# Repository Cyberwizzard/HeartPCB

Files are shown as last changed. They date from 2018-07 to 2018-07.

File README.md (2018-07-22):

# HeartPCB - PCB with LEDs forming an illuminated and animated heart
Firmware and PCB layout for a heart shaped PCB with LEDs.

## About
I designed this PCB and the corresponding firmware as a wedding present for all guests attending. The PCB is the size and shape of a standard coaster, so that it could be used during the party by all guests to put their glass on top of it. When they go home they get a small plastic back containing the components to complete the kit.

The PCB has 18 LEDs, divided into 10 groups and is driven by a) an Arduino Pro Mini of b) statically lit by soldering some pads together.

## Option A
The simple build involves 8 x 47 Ohm and 2 x 150 Ohm resistors, a USB mini connector and 18 red 3mm LEDs.

Solder in place and solder the pads in the middle of the heart together. When plugged in, all LEDs will turn on.

## Option B
When using with an Arduino Pro Mini, there are a number of animations which are played. There are 2 buttons: the brightness button changes the brightness of all LEDs, the fast-forward button switches to the next animation. It supports a demo mode in which animations automatically cycle: hold down brightness until the animation is interrupted and the top-middle LED is on, keep pushing as more and more LEDs come on blinking. The more LEDs blink, the longer the animation is displayed before switching to the next. Set to 0 blinking LEDs to stop automatically forwarding.

The firmware saves the settings and state in the EEPROM (with write wear-levelling) every time the animation changes or the settings are changed.

The component list is 8 x 47 Ohm, 2 x 150 Ohm, 12 x 10k Ohm, USB mini connector, 18 red 3mm LEDs, 2 x 5x5mm push buttons, 1 x 470uF or 1000uF capacitor, 1 x Arduino Pro Mini (ATMEGA328 5V 16MHz)

### Troubleshooting
I had one board getting corrupted after the USB power bank feeding it got empty - my guess is EEPROM corruption. It got stuck loading some invalid stuff and the error LEDs kept turning on.
I fixed this by making error reporting optional and disabled (for production).

If the board does not start correctly due to EEPROM corruption, hold down any button while booting it.
It will now ignore the EEPROM and start the first animation. Press the fast-forward button to skip to the next animation and saving new settings to EEPROM.

## When using this project
Feel free to base your own gift off this design; drop me a note if you do as its nice to hear if this stuff is used again.

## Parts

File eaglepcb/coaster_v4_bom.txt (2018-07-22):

Partlist exported from D:/Users/Documents/eagle/heart_coaster/coaster_v4.sch at 4-5-2018 10:43

1  x 1000uF POLARIZED CAPACITOR
1  x USB CONNECTOR
1  x PIN HEADER 1X6
18 x LED RED 3MM
2  x RESISTOR 0207/7 150 OHMS
12 x RESISTOR 0207/7 10K OHMS
8  x RESISTOR 0207/7 47  OHMS
2  x MICROSWITCH 5MM
1  x ARDUINO PRO MINI (ATMEGA328)

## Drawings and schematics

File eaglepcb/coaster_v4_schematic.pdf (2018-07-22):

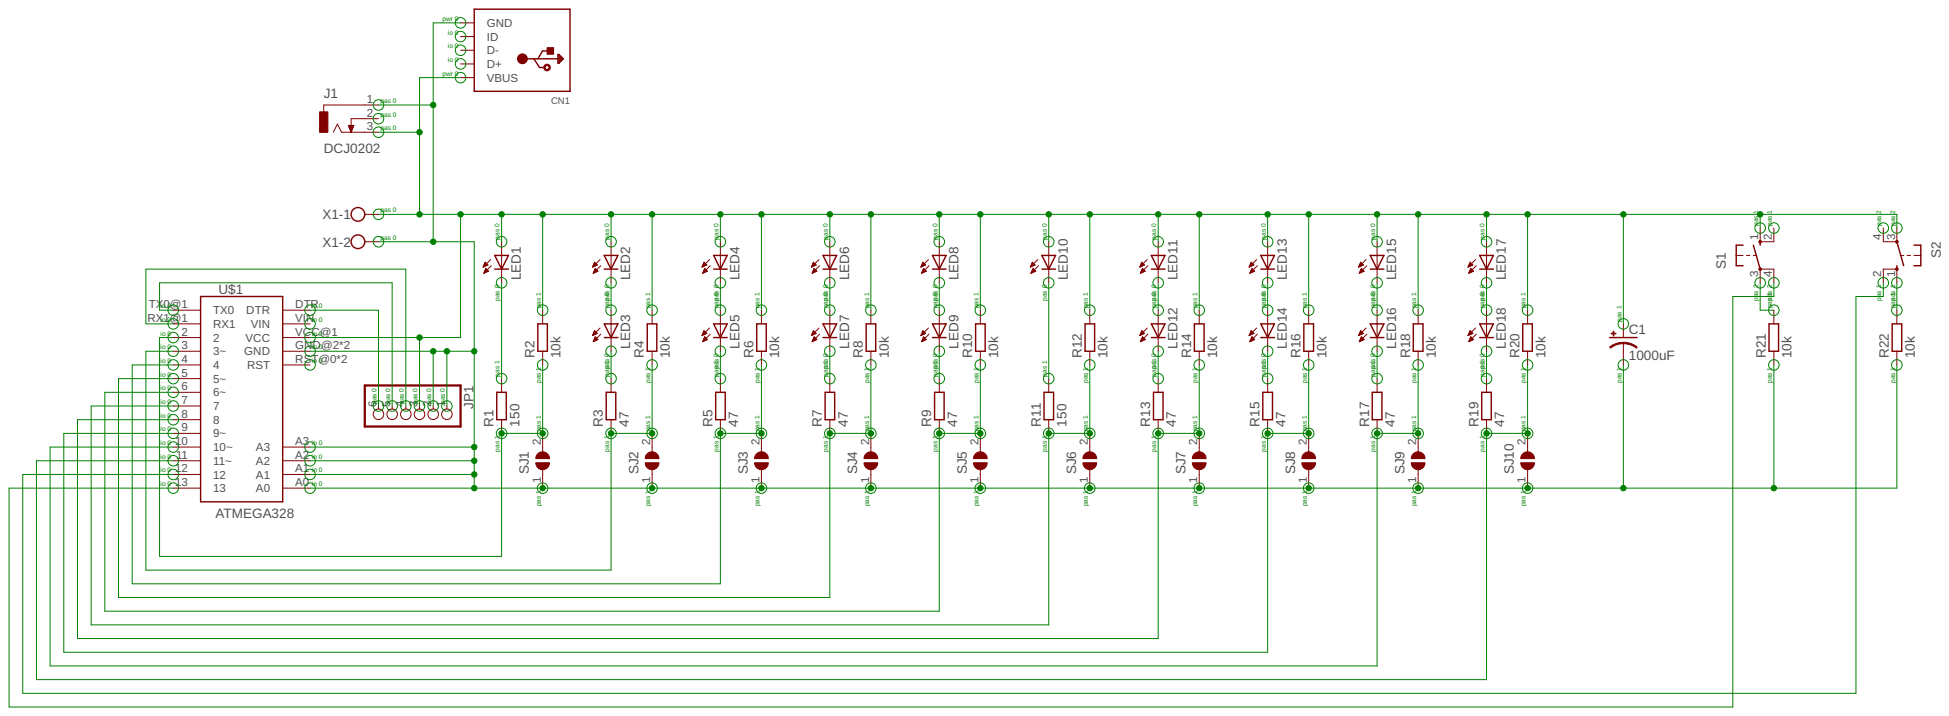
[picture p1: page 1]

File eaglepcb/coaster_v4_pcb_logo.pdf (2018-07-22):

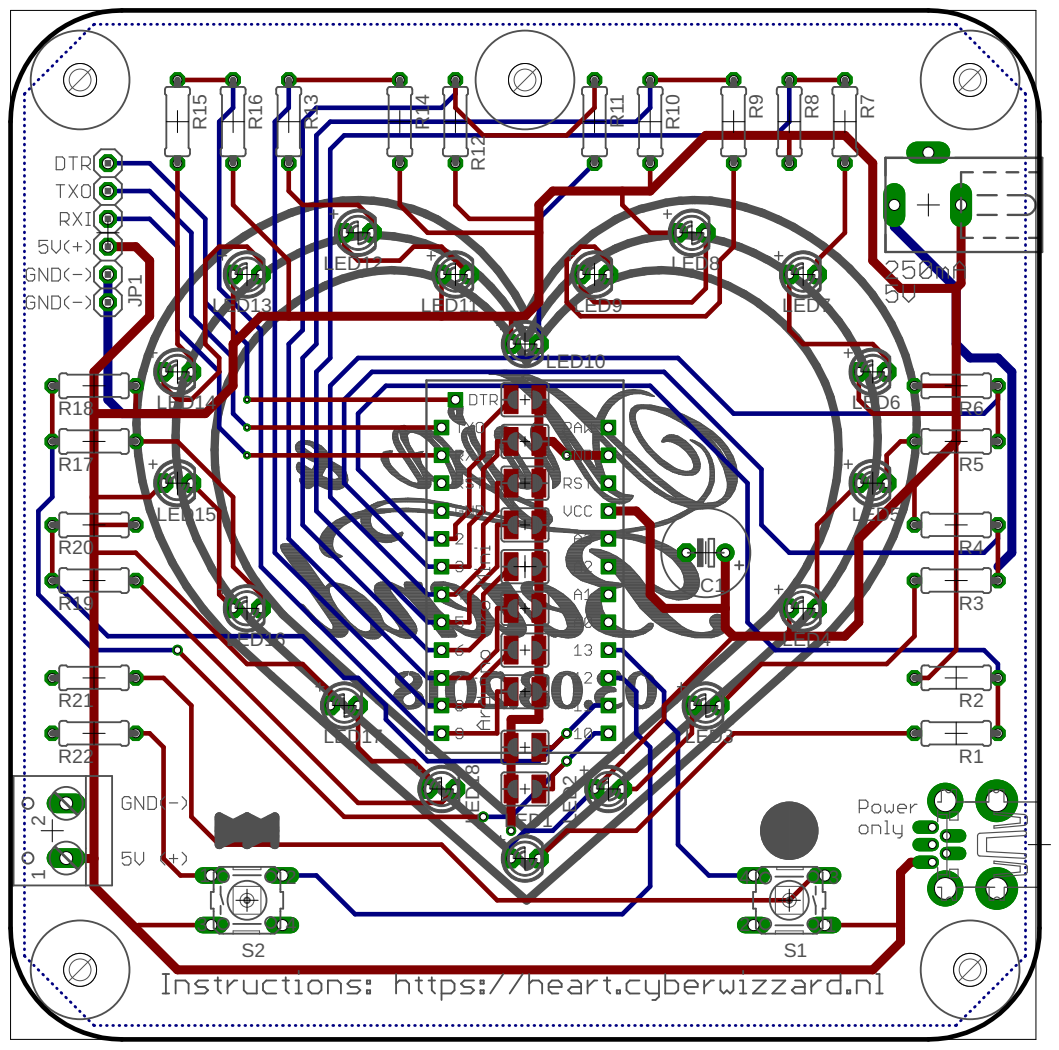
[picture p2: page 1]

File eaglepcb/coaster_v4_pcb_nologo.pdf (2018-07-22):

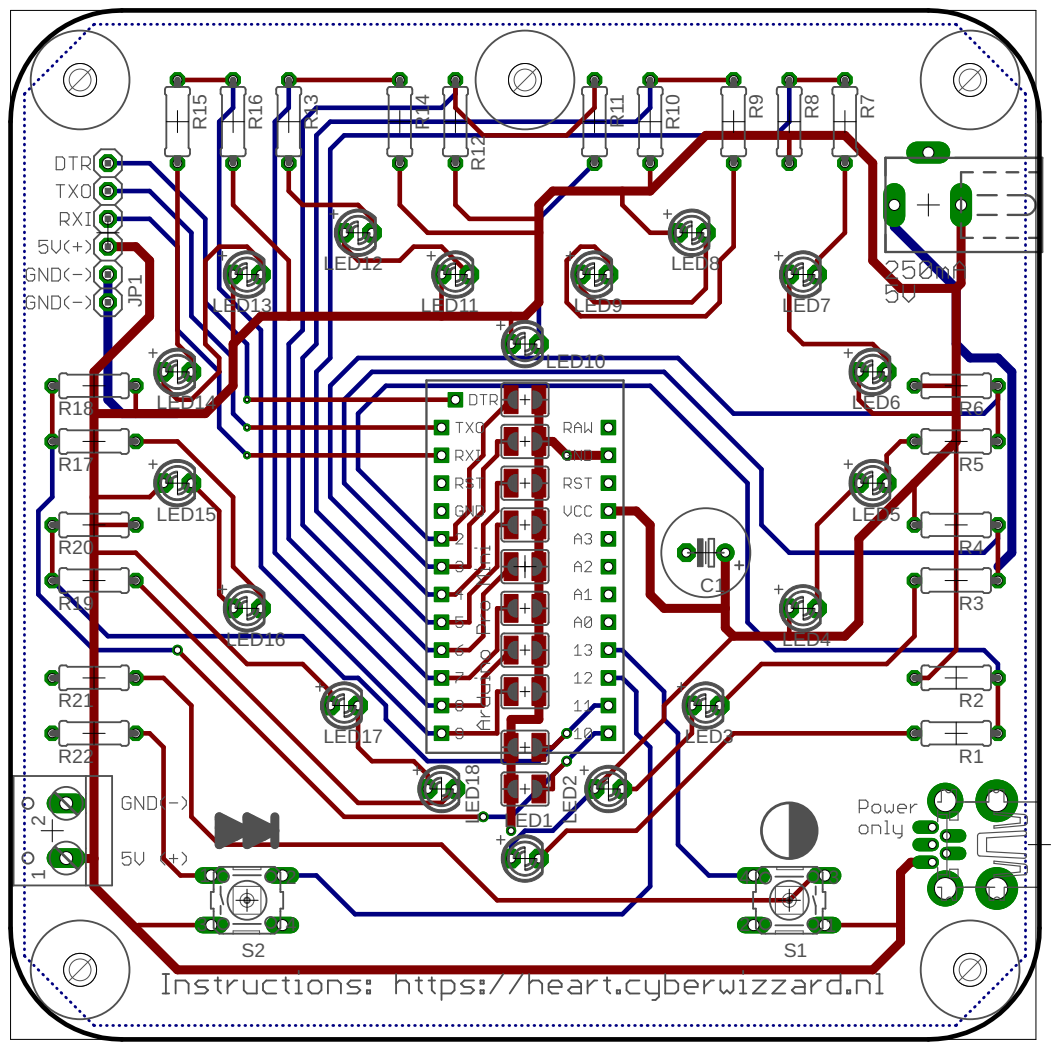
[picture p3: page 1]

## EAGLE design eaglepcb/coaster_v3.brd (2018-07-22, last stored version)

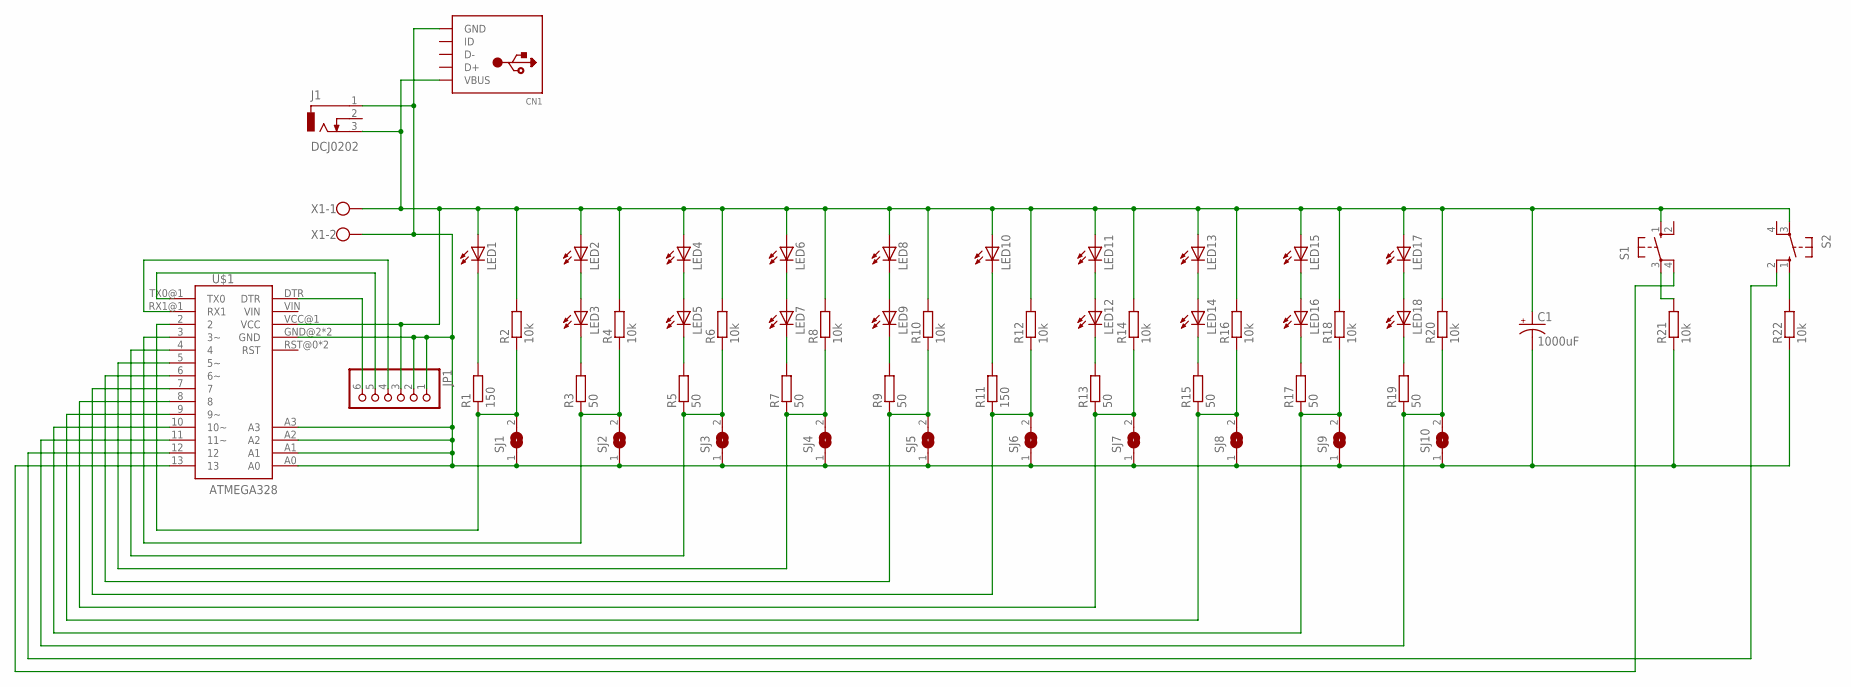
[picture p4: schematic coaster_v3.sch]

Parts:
C1: 1000uF; E3,5-8
CN1: USBTHM; USB-MINIB-THM
J1: DCJ0202
JP1: PINHD-1X6; 1X06
LED1, LED2, LED3, LED4, LED5, LED6, LED7, LED8, LED9, LED10, LED11, LED12, LED13, LED14, LED15, LED16, LED17, LED18: LED3MM
R1, R11: 150; 0207/7
R2, R4, R6, R8, R10, R12, R14, R16, R18, R20, R21, R22: 10k; 0207/7
R3, R5, R7, R9, R13, R15, R17, R19: 50; 0207/7
S1, S2: 10-XX; B3F-10XX
SJ1, SJ2, SJ3, SJ4, SJ5, SJ6, SJ7, SJ8, SJ9, SJ10: SJW
U$1: ATMEGA328; ATMEGA328-DX172858-LIGHT
X1: W237-102

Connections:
DTR: JP1.6, U$1.DTR
unnamed: LED1.K (C), R1.2
unnamed: LED10.K (C), R11.2
unnamed: R1.1, R2.1, SJ1.2, U$1.2
unnamed: LED2.K (C), LED3.A
unnamed: LED3.K (C), R3.2
unnamed: R3.1, R4.1, SJ2.2, U$1.3 (3~)
unnamed: LED4.K (C), LED5.A
unnamed: LED5.K (C), R5.2
unnamed: R5.1, R6.1, SJ3.2, U$1.4
unnamed: R21.2, S1.3
unnamed: LED6.K (C), LED7.A
unnamed: LED7.K (C), R7.2
unnamed: R7.1, R8.1, SJ4.2, U$1.5 (5~)
unnamed: LED8.K (C), LED9.A
unnamed: LED9.K (C), R9.2
unnamed: R9.1, R10.1, SJ5.2, U$1.6 (6~)
unnamed: S2.2 (S1), U$1.12
unnamed: R11.1, R12.1, SJ6.2, U$1.7
unnamed: LED11.K (C), LED12.A
unnamed: LED12.K (C), R13.2
unnamed: R13.1, R14.1, SJ7.2, U$1.8
unnamed: LED13.K (C), LED14.A
unnamed: LED14.K (C), R15.2
unnamed: R15.1, R16.1, SJ8.2, U$1.9 (9~)
unnamed: LED15.K (C), LED16.A
unnamed: LED16.K (C), R17.2
unnamed: R17.1, R18.1, SJ9.2, U$1.10 (10~)
unnamed: LED17.K (C), LED18.A
unnamed: LED18.K (C), R19.2
unnamed: R19.1, R20.1, SJ10.2, U$1.11 (11~)
unnamed: S1.4 (P1), U$1.13
unnamed: R22.2, S2.1 (S)
RXI: JP1.4, U$1.RX1@1 (RX1)
TXO: JP1.5, U$1.TX0@1 (TX0)
VCC_5V: C1.+, CN1.VBUS, J1.3, JP1.3, LED1.A, LED2.A, LED4.A, LED6.A, LED8.A, LED10.A, LED11.A, LED13.A, LED15.A, LED17.A, R2.2, R4.2, R6.2, R8.2, R10.2, R12.2, R14.2, R16.2, R18.2, R20.2, S1.1 (S), S2.3, U$1.VCC@1 (VCC), X1.1
VDD_GND: C1.-, CN1.GND, J1.1, JP1.1, JP1.2, R21.1, R22.1, SJ1.1, SJ2.1, SJ3.1, SJ4.1, SJ5.1, SJ6.1, SJ7.1, SJ8.1, SJ9.1, SJ10.1, U$1.A0, U$1.A1, U$1.A2, U$1.A3, U$1.GND@2 (GND), U$1.GND@3 (GND), X1.2

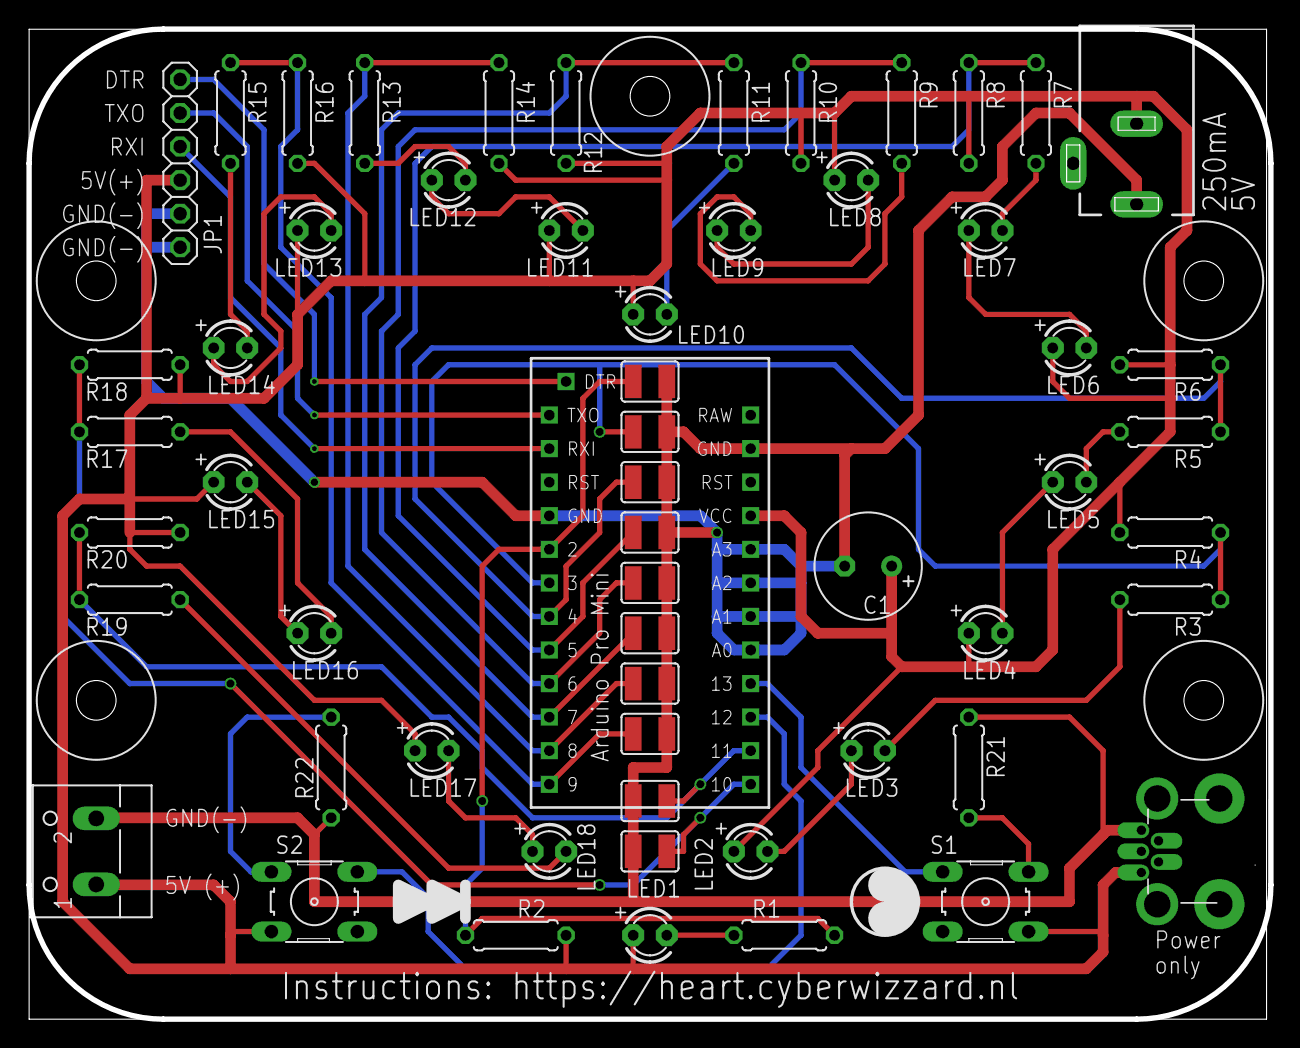
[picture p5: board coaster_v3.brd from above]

Board: 2 copper layers, 94.0 x 74.9 mm, 58 parts (0 on the bottom side), 37 nets.

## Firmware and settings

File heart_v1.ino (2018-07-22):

#include "heart_settings.h"
#include "heart_isr.h"
#include "heart_profiling.h"
#include "heart_eeprom.h"
#include "heart_ani_run_around.h"
#include "heart_ani_dropfill.h"
#include "heart_ani_twinkle.h"
#include "heart_ani_beat.h"
#include "heart_ani_setdemodelay.h"
#include "TimerOne.h"

int start_animation = 0;

void setup() {
  // configure relevant pins as outputs
  for(uint8_t l=0; l<NUM_LEDS; l++) pinMode(PIN_LED_START+l, OUTPUT);
  pinMode(PIN_BTN0, INPUT);
  pinMode(PIN_BTN1, INPUT);

  // Initialize measurement support for profiling (when enabled) - also inits Serial
  MEASUREMENT_INIT;
  // Some debug stats; only visible when measurements are enabled
  SERPRINT(TIMER_INTERVAL_US);
  SERPRINT(" us ISR interval (");
  SERPRINT((TIMER_INTERVAL_US * 10000) / 625);
  SERPRINTLN(" cycles)");
  SERPRINT(FADER_UPDATE_TICKS);
  SERPRINTLN(" ticks between faders");
  SERPRINT("Demo ticks: ");
  SERPRINTLN(TIMER_DEMO_CNT_MAX);
  
  // Allow skipping of EEPROM load by holding down a button on power-on
  if(digitalRead(PIN_BTN0) == HIGH || digitalRead(PIN_BTN1) == HIGH) {
    SERPRINTLN("Skipping EEPROM");
  } else {
    // Load settings from EEPROM (if its disabled, defaults are loaded)
    eeprom_load();
    // Apply settings
    demo_mode = eeprom_settings.demo_mode;
    start_animation = eeprom_settings.animation_id;
    SET_BRIGHTNESS_SCALE(eeprom_settings.brightness);
  }
  
  #ifdef SUPPORT_MEASUREMENTS
    delay(200); // Delay slightly in case profiling is enabled so that the serial buffer can flush (otherwise the ISR will not be fast enough and we end up in an error on boot)
    Serial.flush();
  #endif

  //SET_LED_BRIGHTNESS_MAJOR(1, 120);
  //SET_LED_BRIGHTNESS_MAJOR(2, 40);
  //SET_LED_BRIGHTNESS_MAJOR(3, 5);
  //SET_LED_BRIGHTNESS_MAJOR(4, 180);
  //SET_LED_BRIGHTNESS_MAJOR(5, 255);

  //fader[6].delta = 256 * 5;
  //fader[6].active = 1;
  //fader[6].reload = JUMP;
  //fader[6].upper  = 255;
  //fader[6].lower  = 0;

  //fader[7].delta = 20;
  //fader[7].active = 1;
  //fader[7].reload = INVERT;
  //fader[7].upper  = 255;
  //fader[7].lower  = 0;
  SERPRINTLN("OK:0");
  
  // Use timer1 for the intervals for the software PWM and faders
  if(ISR_MINIMUM_INTERVAL_US > TIMER_INTERVAL_US) {
    // Note: the minimum interval is not verifiable at pre-compilation so it has to be at run-time
    // Ensure that when the PWM refresh is set to high that an error condition is shown
    Timer1.initialize(100000); // Initialize to a relatively slow interval of 100ms since this is an error state anyway
    _err = ERR_ISR_INTERVAL_TOO_SMALL;
  } else {
    Timer1.initialize(TIMER_INTERVAL_US); // initialize timer1 and set to a high pace interval
  }

  // Set the ISR for Timer 1
  Timer1.attachInterrupt(heart_isr);

  // Second debug print; when the ISR is set way too high, the serial port dies - this canary will show this issue
//  SERPRINTLN("OK:1");
}

  run_around_setting_struct_t run_around_erasing_speedup = {
    .fade_speed_major = 0,
    .fade_lower       = 0,
    .fade_upper       = 255,
    .fade_up_start    = 255,
    .offset           = 0,
    .delay_base_ms    = 220,
    .delay_tgt_ms     = 50,
    .delay_step_ms    = 10
  };

  run_around_setting_struct_t run_around_erasing_speeddown = {
    .fade_speed_major = 0,
    .fade_lower       = 0,
    .fade_upper       = 255,
    .fade_up_start    = 255,
    .offset           = 0,
    .delay_base_ms    = 50,
    .delay_tgt_ms     = 220,
    .delay_step_ms    = 10
  };

  run_around_setting_struct_t run_around_fade2 = {
    .fade_speed_major = 5,
    .fade_lower       = 0,
    .fade_upper       = 255,
    .fade_up_start    = 235,
    .offset           = 0,
    .delay_base_ms    = 220,
    .delay_tgt_ms     = 50,
    .delay_step_ms    = 10
  };

  run_around_setting_struct_t run_around_pingpong = {
    .fade_speed_major = 20,
    .fade_lower       = 10,
    .fade_upper       = 255,
    .fade_up_start    = 205,
    .offset           = 0,
    .delay_base_ms    = 50,
    .delay_tgt_ms     = 50,
    .delay_step_ms    = 0
    //.delay_current_ms = 0
  };

int first_run = 1; // Flag to skip storing settings in the first run

void loop() {
  int aborted = 0;

  // Second debug print; when the ISR is set way too high, the serial port dies - this canary will show this issue
  SERPRINTLN("OK:1");
  
  while(1) {

    for(int i=0,j=start_animation; i<NUM_ANIMATIONS; i++, j=(i+start_animation)%NUM_ANIMATIONS) {
      MEASUREMENT_PRINT;
      
      if(!first_run) {
        // Save animation switch plus all other settings to EEPROM to resume when power is lost
        eeprom_settings.animation_id = j;
        eeprom_settings.demo_mode = demo_mode;
        eeprom_settings.brightness = GET_BRIGHTNESS_SCALE;
        eeprom_store();
      } else {
        first_run = 0;
      }
      switch(j) {
        case 0:
          // Show a beating heart
          animate_beat();
          break;
        case 1:
          // Animation of 1 runner going around the heart, reversing after 5 rounds
          //animate_run_around(setup = 1, auto_loop = 1, dir = 1, runners = 1, cross = 0, erasers = 0, run_around_setting_struct_t *s = NULL);
          aborted = 0;
          while(!aborted) {
            for(int x = 0; x < 10; x++) {
              aborted = animate_run_around(x == 0, 0, (x < 5) ? 1 : -1, 1);
              if(aborted) break;
            }
          }
          break;
        case 2:
          // Setup, loop, 2 runners, standard direction
          animate_run_around(1, 1, 1, 2);
          break;
        case 3:
          // Animation of 1 runner going around the heart, reversing each round
          //animate_run_around(setup = 1, auto_loop = 1, dir = 1, runners = 1, cross = 0, erasers = 0, run_around_setting_struct_t *s = NULL);
          aborted = 0;
          while(!aborted) {
            for(int x = 0; x < 10; x++) {
              aborted = animate_run_around(x == 0, 0, (x % 2) ? 1 : -1, 1, 0, 0, &run_around_pingpong);
              if(aborted) break;
            }
          }
          break;
        case 4:
          // 3 runners
          animate_run_around(1, 1, 1, 3);
          break;
        case 5:
          // 2 runners, one cross
          animate_run_around(1, 1, 1, 2, 1); // 2 runners, one cross
          break;
        case 6:
          // 2 runners, one erasers
          aborted = 0;
          while(!aborted) {
            for(int i = 0; i < 10; i++) {
              aborted = animate_run_around(i == 0, 0, 1, 4, 0, 1, &run_around_erasing_speedup); // 2 runners, one erasers
              if(aborted) break;
            }
            if(aborted) break; // break out of while to prevent entering the next for()
            for(int i = 0; i < 10; i++) {
              aborted = animate_run_around(i == 0, 0, 1, 4, 0, 1, &run_around_erasing_speeddown); // 2 runners, one erasers
              if(aborted) break;
            }
            
          }
          break;
        case 7:
          // Slowly filling heart
          animate_dropfill();
          break;
        case 8:
          // Starry twinkle
          animate_twinkle();
          break;
      } 
      // If tbtn0 was held down, show the delay configuration panel
      if(btn0_hold) {
        animate_setdemodelay();
        i--; // Return to the current animation
      }
      
    }
  }
  
  
  

  //for(int i=0; i<10; i++) animate_run_around(i == 0, 1, 3); // 3 runners
  //for(int i=0; i<10; i++) animate_run_around(i == 0, 1, 4); // 4 runners
  //for(int i=0; i<10; i++) animate_run_around(i == 0, 1, 5); // 5 runners

  //for(int i=0; i<10; i++) animate_run_around(i == 0, 1, 2, 1); // 2 runners, one cross
  //for(int i=0; i<10; i++) animate_run_around(i == 0, 1, 4, 1); // 4 runners, two cross



  //for(int i=0; i<10; i++) animate_run_around(i == 0, 1, 4, 0, 1, &run_around_erasing); // 2 runners, one erasers
  
  /*
  for(int i=0; i<10; i++) animate_run_around(i == 0, 1, 2, 0, 0, &run_around_fade2); // 2 runners
  if(run_around_fade2.delay_tgt_ms == run_around_fade2.delay_current_ms) {
    uint16_t swap = run_around_fade2.delay_tgt_ms;
    run_around_fade2.delay_tgt_ms = run_around_fade2.delay_base_ms;
    run_around_fade2.delay_base_ms = swap;
  } */
}

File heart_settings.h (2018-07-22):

/**
 * heart_settings.h - Heart PCB Project - Settings file for project
 * 
 * @author  Berend Dekens <berend@cyberwizzard.nl>
 * @version 1
 * @date    2018.04.13
 * @license GNUGPLv3
 */
#ifndef _HEART_SETTINGS_H_
#define _HEART_SETTINGS_H_

#include "stdint.h"

// ------------------------- Debug Settings ----------------------------

// Define to enable profiling support; slows down the program and enables serial debugging
// Comment out when not debugging the project!
//#define SUPPORT_MEASUREMENTS

// Define to enable measurements within the ISR; slows down the critical section of the interrupt routine so
// only enable when optimizing the interrupt routine.
// Comment out when not debugging the project!
//#define SUPPORT_ISR_MEASUREMENTS

// ------------------------- LED Settings ----------------------------

// When fading in up to a new lower bound on the LED brightness, use this speed for all animations.
// This essentially is used when 'wiping' the previous LED brightness to the start state of the current animation.
// Default: 5
#define SETUP_FADE_SPEED_MAJOR 5

// GPIO pin to LED mapping; by default LED0 is connected to pin 2, LED1 to pin 3 etc.
// !!!WARNING!!!: DO NOT CHANGE THESE SETTINGS AS THE INTERRUPT LOGIC IS HARDCODED TO THE ORIGINAL SETTINGS
#define PIN_LED_START 2
#define NUM_LEDS 10
#define PIN_LED_END (PIN_LED_START+NUM_LEDS)

// ---------------------------- Demo Settings --------------------------------
// Set this to the number of seconds before automatically switching effects (only when demo mode is on)
#define EFFECT_DURATION_S 20

// ---------------------------- Button Settings --------------------------------
#define PIN_BTN0 13
#define PIN_BTN1 12

// ------------------------- PWM and fader Settings ----------------------------

// PWM frequency, setting this to 100 means PWM_STEPS * 100 calls per second to callback() to update the PWM, and LEDs will turn off and on 100 times a second
// More is better (prevents flicker), but too high will eat up CPU without leaving time for the animation resulting in choppy animations
// Default: 75 Hz
#define TIMER_FREQ 100

// Fader update frequency, setting this to 10 means a fade in or out is updated 10 times per second. Note that changing this setting changes the speed of a fade.
// Note: since the PWM frequency and length dictates the timer interval, this setting will be converted in a derrived frequency.
#define FADER_UPDATE_FREQ 15

// DO NOT CHANGE - PWM length - note: should be a power of 2 and matching of the type of _pwm_step
#define PWM_STEPS 255

// DO NOT CHANGE - Timer delay in us based on the requested update frequency
#define TIMER_INTERVAL_US (1000000 / ((uint32_t)(TIMER_FREQ) * (uint32_t)(PWM_STEPS)))

// DO NOT CHANGE - Compute how many timer interrupts are needed of the PWM update to span one interval for the fader update frequency
#define FADER_UPDATE_INTERVAL_US ( 1000000 / (uint32_t)(FADER_UPDATE_FREQ) )
// FIXME For some reason it seems the frequency is off by a factor three: at 50 Hz, a fader with delta set to major 5, in one second the value 250 should be reached, but it takes roughly 3 seconds instead...
#define FADER_UPDATE_TICKS       (( FADER_UPDATE_INTERVAL_US ) / ( ( TIMER_INTERVAL_US ) * 3) )

// DO NOT CHANGE - The ISR has been profiled to take between 8us and 20us, together with overhead from other code, it turns out 34us is the minimum interval
// needed to prevent nested interrupts from occuring. Note that only when SUPPORT_NESTED_ISR is defined, is it possible to get nested interrupts, without it ticks of the timer will simply be skipped.
#define ISR_MINIMUM_INTERVAL_US 34

// This define is only needed during development and benchmarking of the ISR (interrupt routine) to enable nested interrupts; after development it should be disabled
//#define SUPPORT_NESTED_ISR

// Compute how many ISR fader ticks (which happen once every 255 ISR calls) make up the duration of the demo mode delay between effects
// FIXME also this is off by a factor 6
#define TIMER_DEMO_CNT_MAX (uint32_t)(((uint64_t)EFFECT_DURATION_S * 1000000 * 6) / ((uint64_t)FADER_UPDATE_INTERVAL_US))

// ------------------------- Error Mode Settings ----------------------------

// Define to support error reporting - disable for production builds
//#define SUPPORT_ERRORS

// If something goes wrong, these 2 LEDs will be statically on
#define PIN_LED_ERR0 2
#define PIN_LED_ERR1 7

// To indicate that an error occured, count up to this value using the ISR to blink the LEDs on PIN_LED_ERR0 and PIN_LED_ERR1
#define ERROR_BLINK_CNT 4000
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

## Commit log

2018-04-12 Implemented nested interrupts, causes visual glitches
    [heart_settings.h, heart_v1.ino]
2018-04-13 Optimized ISR to less than 24us, fixed run-around animation
    [heart_settings.h, heart_v1.ino]
2018-04-22 Added twinkle effect, implemented button handling, fixed various things
    [heart_ani_run_around.cpp]
2018-07-22 Error reporting optional and disabled, added EEPROM skip via button on boot
    [heart_isr.cpp, heart_settings.h, heart_v1.ino]
2018-07-22 Added PCB source files
    [coaster_v3.brd, coaster_v3.sch]
2018-07-22 Updated PCB files to v4
    [coaster_v3.brd, coaster_v3.sch]
